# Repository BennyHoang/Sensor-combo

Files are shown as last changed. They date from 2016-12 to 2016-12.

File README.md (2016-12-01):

# Sensor-combo
M2M solution

# Oppgavebeskrivelse
Skolen har akkurat flyttet inn i nytt bygg og vi har opplevd at luften noen ganger er dårlig i klasserommene. Målet for eksamen i M2M er å ende opp med noe som kan bli
en permanent løsning for å overvåke læringsmiljøet, slik at man på sikt kan få det bedre. Dataene som løsningen samler inn skal brukes av elevene på M2M faget, men
også av Driftsavdelingen og andre linjer ved skolen. Det må derfor publiseres på en plattform som er enkelt tilgjengelig for alle som ønsker tilgang.
Sensor-nodene skal samle inn data om temperatur, fuktighet, lysnivå, bevegelse og CO2-nivå målt i PPM. Å sørge for at sensorene produserer riktige data er en del av
oppgaven, så om man trenger å gjøre kalibrering eller andre tilpasninger må dette dokumenteres. Hvordan man tenker å bygge og plassere nodene bør også
dokumenteres.

Sensor-noden skal lages med enten LoRa radio eller Particle Photon:
- Velger man LoRa radio, må man skrive en liten Gateway som kan sende dataene videre til internett. Om noen av dere trenger å låne en ekstra LoRa radio som Gateway,
gi meg beskjed så snart som mulig. Det er ikke krav om å bruke PubSub for LoRa, da jobbing med Gateway er forventet å ta litt ekstra tid.
- Velger man Particle Photon må man basere klienten på en PubSub løsning (f.eks. MQTT).
Du må argumentere for hvorfor du velger den ene fremfor den andre løsningen. Det at vi har mer erfaring med Photon bør ikke være et argument.
I tillegg til en radio, skal man ha med følgende sensorer i noden:
- DHT11 sensor
- Photoresistor
- PIR sensor
- MH-Z19 CO2 sensor (ikke MQ7 som er en CO-sensor!)

Sensor-nodene skal rapportere og lagre dataene på en valgfri skytjeneste. Det skal lages en klient som bør fungere på enten mobil eller stasjonær PC. Her skal man
kunne lese av status for mer enn ett rom og det bør også være mulig å kunne se historiske data. Klienten bør minimum ha en grafisk fremstilling av dataene over tid.

Det må lages en trinnvis dokumentasjon for hvordan man setter opp både klient og server. Denne skal være enkel å følge for en som ikke har samme erfarings-grunnlag
som vi har bygget opp i løpet av skoleåret. Den dere skriver dokumentasjonen for er altså en som ikke har brukt Photon eller LoRa Feather noe særlig før. Alle valg av
tjenester må begrunnes og det må dokumenteres hvordan løsningen skal kunne skaleres til å dekke både Fjerdingen og Vulkan Campus. 

Utover selve oppgaven skal det leveres dokumentasjon og kode som beskriver:
- Sensornode m/nødvendige biblioteker
- Skytjeneste
- Klient
- Skalering av løsningen utover en enkelt node
- Sikkerhet
- Valg av radio-løsning

Dokumentasjonen skal inneholde en video som viser hele løsningen i bruk. Den skriftlige dokumentasjonen bør være såpass god at andre skoler også kan sette opp en
tilsvarende løsning.
OBS!

Sensor-delen av denne oppgaven har dere langt på vei allerede gjort, men det holder ikke å lagre data til Particle Cloud. Denne oppgaven bygger videre på den første og
målet er at dere har bygget en komplett ende til ende implementasjon av et sensor-nettverk. Hvis dere skrev god dokumentasjon på sensor-noden i Oppgave 1, kan dere
gjerne gjenbruke noe av dette, men både klient og server-løsning er annerledes og må dokumenteres skikkelig. I tillegg skal kommunikasjonen med server-tjenesten være
annerledes enn i forrige løsning, så det bør være litt av hvert å bryne seg på her!

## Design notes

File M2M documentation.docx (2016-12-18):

# Documentation

# Oppgaven

Oppgaven går ut på å lage en løsning som kan overvåke løringsmiljøet slik at man på sikt kan få bedre oversikt over skolen sin tilstand.

Video: https://www.youtube.com/watch?v=nkPM_7XQKms

# Valg av enhet

Løsningen er bygget opp med Particle Photon som tar i mot data og sender dem til Microsoft sitt skytjeneste. Grunnen til at det ble valgt Particle Photon over LoRa radio er fordi løsningen kan lett bli satt opp uten å måtte konfigurere radiofrekvens etter hvor man befinner seg. Dette betyr at løsningen kan enkelt settes opp i en skole i Kina uten å måtte gjøre noe ekstra spesial tilpasninger.

LoRa frekvenser

- EU: 863-870 Mhz
- AU: 915-928 Mhz
- US: 902-928 Mhz
- CN: 779-787 Mhz

I tillegg til dette må man planlegge hvordan man skal sette opp infrastrukturen til LoRa. Man må stille spørsmål som:

- Hvilken rekkevidde får vi innendørs?
- Klarer vi å nå helt ned i kjelleren?
- Hvor bør Gateaway-radion stå?

Med Particle Photon, som har tilgang til wifi slipper man å tenke på alt dette. Her trenger man bare å tenke på hvor i rommet man skal plassere sensor-noden. I tillegg til dette har Particle en veldig bra dokoumentasjon på hvordan man kan sende data over HTTP. Dette gjør det lettere å kunne koble seg til en skytjeneste (i dette tilfellet Microsoft Azure).

# Arkitektur

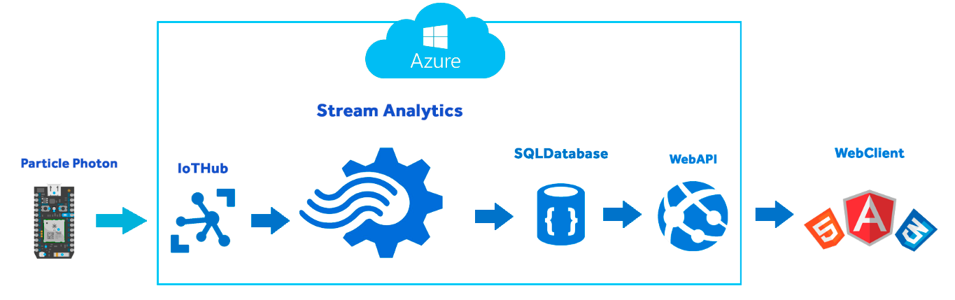
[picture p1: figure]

Her er en figur som illustrer hvordan dataen flyter fra enheten til nettsiden. IoT hub ligner veldig mye på EventHub, men den støtter 2-veis kommunikasjon over protokoller som MQTT eller AMQP. I tillegg til dette har Azure IoT hub «device management> der man kan registrere og forvalte alle sine enheter fra ett sted. MQTT gir for eksempel fordelen av å ha mindre «overhead» i protokollen, samt at den støtter callback funksjonalitet, dvs at du kan trigge metoder direkte på device. På den andre siden har Particle Cloud API også veldig god støtte for å snakke med enheten din på sin side. Les mer her om Azure IoT hub vs Azure Event Hub: https://docs.microsoft.com/en-us/azure/iot-hub/iot-hub-compare-event-hubs

## Setup Azure IoT Hub

For å kunne sette opp Azure IoT Hub, trenger du først en microsoft konto(outlook.com). Deretter kan du registrere Azure kontoen din her: https://azure.microsoft.com/nbno/free/?WT.srch=1&wt.mc_id=AID_SEM_

Particle og Microsoft nå partnere, så dette gjør det mye enklere å kunne integrere enheten mot microsoft sine produkter. Dette gjør det mulig for oss å bruke andre tjenester i Azure som:

- Azure Machine Learning (Predikere sensordata?)
- Notification Hub
- Stream Aanalytics
- PowerBI

Gjennom hele prossessen I opprettelse av applikasjoner i Microsoft Azure kan det lønne seg å være tålmodig da det tar tid før ting er ferdig opprettet.

For å kunne sette opp Azure IoT Hub må du navigere deg til Azure portalen: www.portal.azure.com Trykk på + ikonen på sidebaren, deretter trykk på Internet of Things > IoT Hub

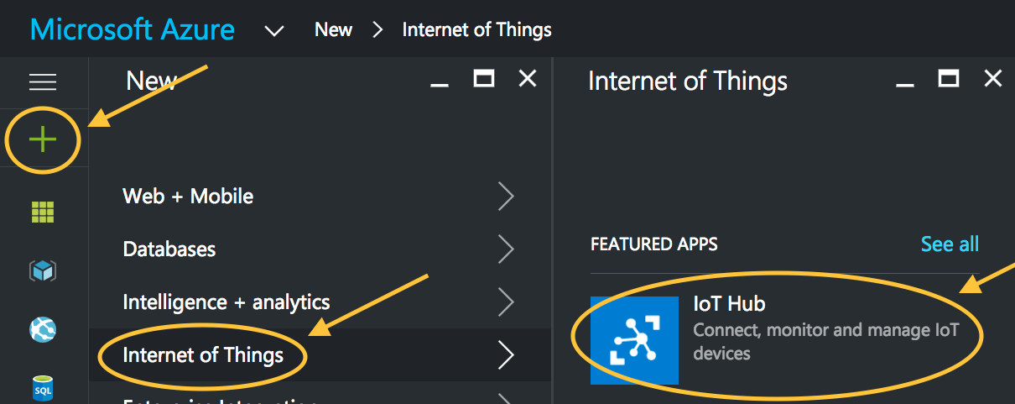
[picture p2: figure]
Create an IoT Hub

(Hvis du har vanskeligheter med å finne den, kan du også søke på IoT Hub i søkebaren)

Deretter vil en ny fane poppe opp, bruk disse instillingene hvis du vil teste løsningen fort og eksperimentere uten at ting skal koste penger. Det vil ta litt tid før IoT Huben din er oppe og kjører.

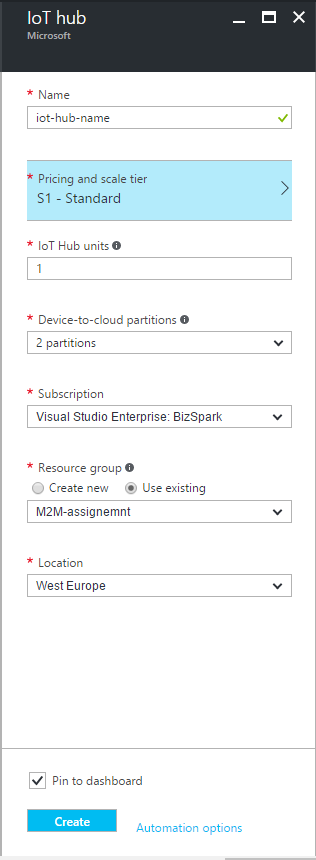
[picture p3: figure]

Hvis du velger Free-plan vil det ikke være mulig å oppgradere den til en av de andre tier i senere tidspunkt. Velger du Free vil det bare være for testing. Navnet til IoT-huben må du huske til senere for å kunne lykkes med integreringen. Bruk også resource group for å lett kunne gruppere dine applikasjoner under en gruppe. Dette gjør det lettere hvis du skal slette den til senere tidspunkt.

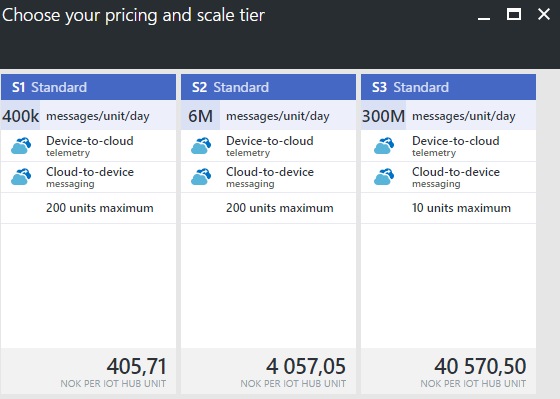
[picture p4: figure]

Det er ganske mye man kan gjøre for bare 405 kr i mnd (prisene endrer seg etter som valutakursene endrer seg). Dette avhenger selvfølgelig på hvor ofte du sender meldinger og hvor mange enheter som sender meldinger til IoT Huben.

Legg til Shared Access Policy

For å gjøre det mulig for Particle å snakke med IoT huben din, må du legge til en shared access policy. Dette er også på grunn av sikkerhetsmessige årsaker, med shared access policy lager du en regel som bare gjelder for din particle integrasjon. Når IoT Huben er ferdig spunnet opp, klikk på ikonet fra dashboardet, deretter klikk på shared access policies > + Add. Gi din policy write, read og device connect permissions.

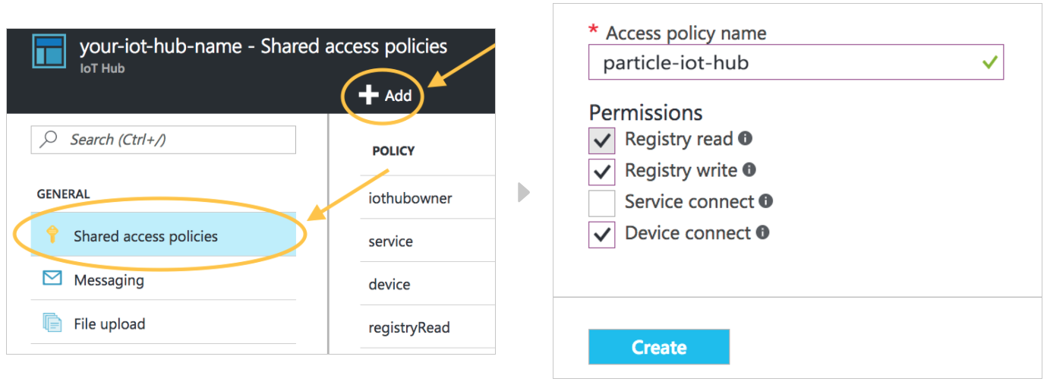
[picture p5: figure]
Create shared IoT Hub policy

For at din particle enhet skal kunne ha vellykket integrasjon trenger du begge policy name og policy primary key. Du kan finne dette ved å klikke på policy navnet som du nettop har opprettet.

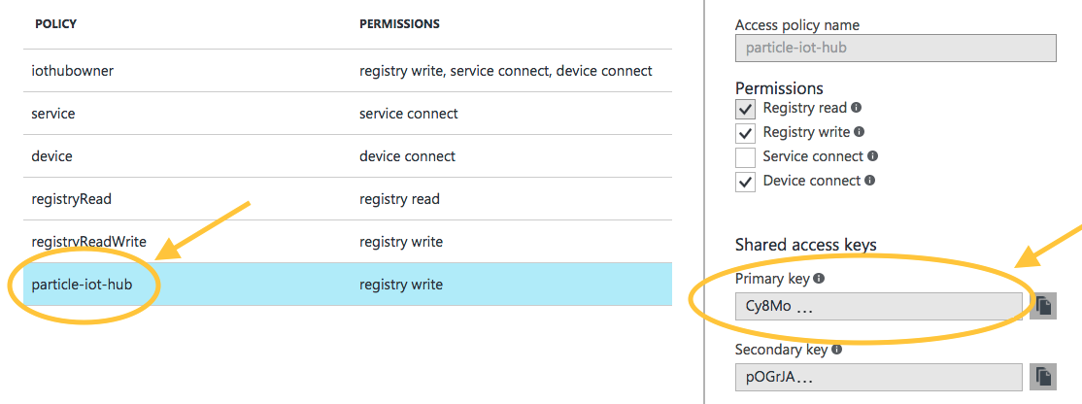
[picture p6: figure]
Access shared IoT Hub policy info

Alle nøkkler fra applikasjonene i Azure har ending med « = », hvis du er usikker på at du har kopiert hele koden, kan du se på slutten av strengen om den har « = ». Ellers kan du klikke på ikonet for å kopiere nøkkelen. Når dette er ferdig kan vi begynne å konfigurere instillingene i Particle.

## Particle Console

Naviger deg inn til www.console.particle.io for å aktivere Azure IoT Hub Integration.

(Den er fortsatt under beta, så noe kan være litt ustabilt)

Videre i konfigurasjonen vil du støte på disse feltene:

- Event Name: Dette er navnet på eventet som vil trigge datapublisering til Azure IoT Hub. Dette vil bli trigget når du kaller på Particle.publish() metoden fra Particle.
- IoT Hub Name: Navnet som du ga IoT Huben. I dette tilfellet: iot-hub-name
- Shared Access Policy Name: Navnet til Shared Access Policy. I dette tilfellet: particle-iot-hub
- Shared Access Policy Key: Nøkkelen fra shared access policy name
- Device: Hvis du vil at dette skal gjelde alle particle enheter, velg: “Any”, hvis du vil at det bare skal gjelde din enhet må du velge enheten med respective navn.

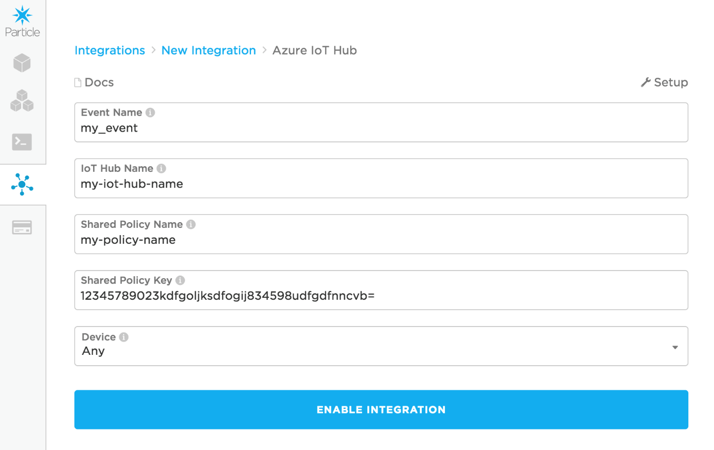
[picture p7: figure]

Videre klikker du på Advanced settings for å kunne sende din spesial tilpasset JSON. Hvordan webhook variablene fungere kan du lese mer om her: https://docs.particle.io/guide/tools-and-features/webhooks/#webhook-variables

Kode:

{

"carbondioxide": "{{C2}}",

"temperature": "{{t}}",

"humidity": "{{h}}",

"light": "{{l}}",

"motion": "{{m}}",

"timecreated": "{{SPARK_PUBLISHED_AT}}",

"guid": "{{SPARK_CORE_ID}}",

"location": "{{loc}}"

}

# Particle Photon

Utstyrsliste for Particle Photon:

- MH-Z19
- DHT11
- Photoresistor
- PIR

Før du i det heletatt begynner å koble opp hele systemet og laste opp kode, kan det lønne seg å bare koble hvert komponent hver for seg og teste hver for seg. Dette kan du f.eks gjøre ved å teste gjennom analogRead(PIN).

Set up Particle Photon: https://docs.particle.io/guide/getting-started/start/core/

## Koblingsskjema

PIR | Particle Photon | Data
VCC | VCC | Bevegelse
Data | D0
GND | GND

DHT11 | Particle Photon | Data
VCC | VCC | Temperatur: Celcius & Farenheit Fuktighet
GND | GND
D-OUT | D2
A-OUT | Ingen

Photosensor | Particle Photon | Data
A-OUT | A5 | Lys
GND | GND

MH-Z19 | Particle Photon | Data
PWM | D1 | CO2 (Carbondioksid)
GND | GND
VCC | VCC

Jeg fant ikke delen for MH-z19 i fritzing, men det holder nok å forholde seg til koblingsskjema også. Vær oppmerksom på at PIR-sensoren kan oppføre seag litt merkelig i starten. Da hjelper det å justere Sensetivity og delay.

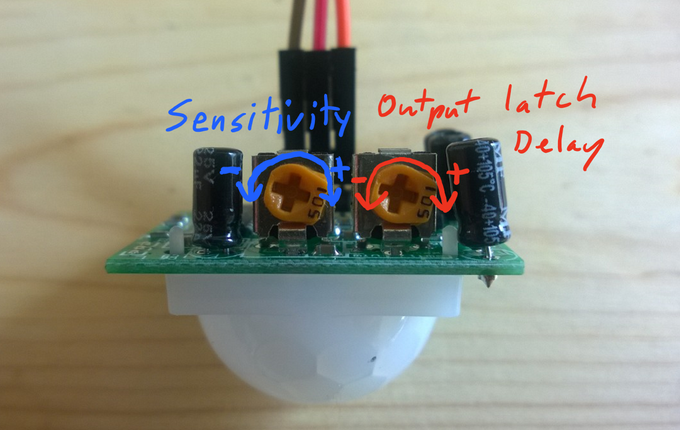
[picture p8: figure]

## Kode

Til dette prosjektet lastet jeg ned local IDE for å kunne jobbe med filer. Fordelen med dette er når man har så mange sensorer som nå, blir det lettere å lage objekter av sensorene. IDE kan lastes ned her: https://www.particle.io/products/development-tools/particle-local-ide

Ulempen med IDE-et er at man ikke kan inkludere biblioteker på like lett måte som online IDE-et. Dette må du selv laste ned og legge til i prosjektet. En løsning på dette (som jeg gjorde) var å gå inn på online IDE, finne det biblioteket jeg ville ha og replikere filene i local IDE.

Deretter, for at alle .h filer skal fungere må du inkludere #include "application.h" i respektive .filer. Dette er for å kunne bruke Particle sitt bibliotek.

Det er også mulig å bruke www.build.particle.io men da må du være oppmerksom på at oppdelingen av sensorene ikke vil fungere. Du må legge alle koden i en fil.

## Test om data blir sendt

Det finnes flere måter å se om dataen blir sendt. Fra particle sin side holder det å sjekke ut consoll loggen fra nettleseren eller ved å kjøre particle subscribe mine fra CLI. Jeg har forholdt meg til consollen nettleseren.

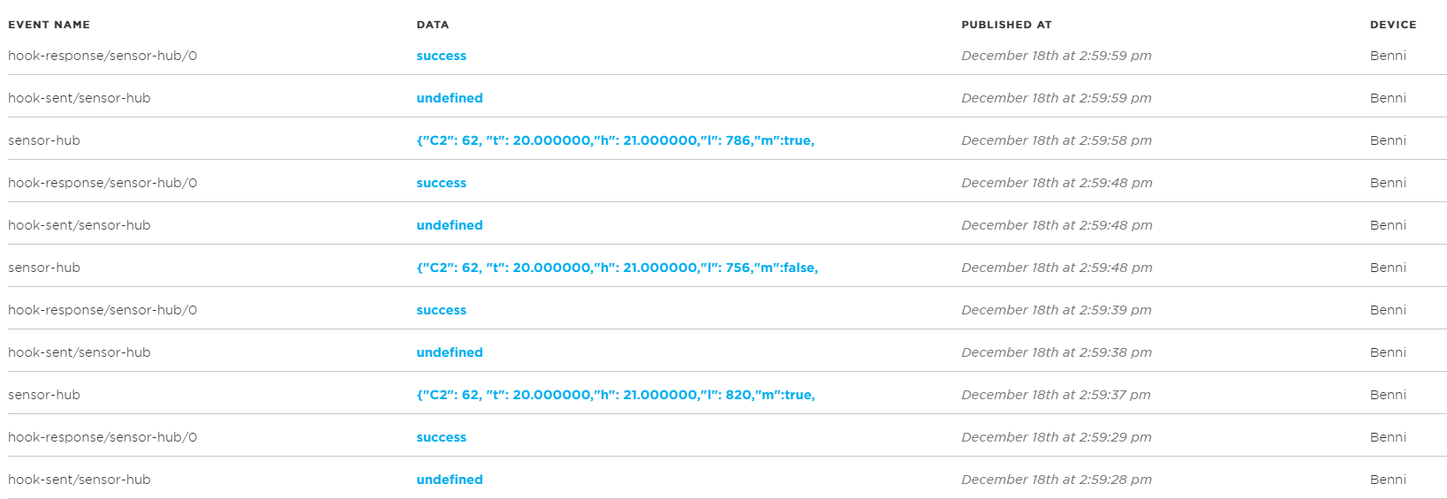
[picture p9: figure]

Fra Azure sin side kan det lønne seg å sjekke ut iothub-explorer som er en npm-pakke. https://github.com/Azure/iothub-explorer

Når alt er på plass og meldingene blir sendt uten error vil particle enheten din bli registrert i IoT Huben.

Du vil også kunne se om kvoten din per dag blir brukt opp eller ikke.

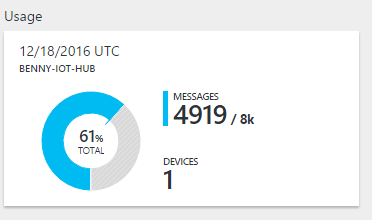
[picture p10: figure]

## Stream Analytics

På grunn av tid og erfaring vil denne delen skje gjennom den gamle portalen. Det er ingenting i veien å gjøre dette gjennom den nye portalen, men forrige oppgave var jeg avhengig av å gjøre alt i gamle portalen på grunn av støtte for Service bus og eventhub. Ingenting i den denne løsningen er egentlig avhengig av den gamle portalen.

Naviger til www.manage.windowsazure.com

Stream Analytics er det verktøyet vi vil bruke for å kunne sveise sammen data fra enheten og skrive til en database. Den fungerer som en publisher og en subscriber. I dette tilfellet vil den ta inputstream fra IoT Hub og deretter output til en SQL-Database. Meldingene som blir sendt til IoT Hub vil bli slettet over tid og derfor trenger vi SQL-Database til å kunne lagre historiske data.

For å opprette database trykker du på SQL Databases og trykk på new

Når databasen er ferdig opprettet må vi legge til tabeller og attributter. For å gjøre dette lett, klikk inn på Open in Visual Studio

Let etter SQL serveren som databasen ligger i og opprett ny tabell.

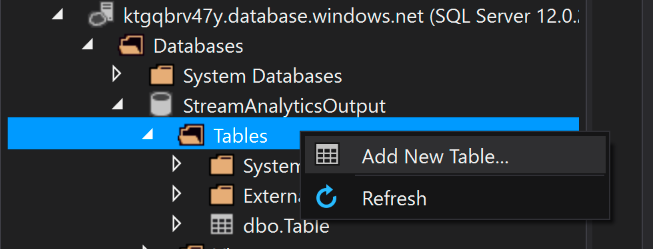
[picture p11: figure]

Det går ann å bruke Databasedesign vinduet til å legge til i databasen, men lim inn dette for å spare tid.

CREATE TABLE [dbo].[Table] (

[Id] INT IDENTITY (1, 1) NOT NULL,

[temperature] FLOAT (53) NULL,

[humidity] FLOAT (53) NULL,

[light] INT NULL,

[motion] NVARCHAR (MAX) NULL,

[timecreated] DATETIME NULL,

[guid] NVARCHAR (MAX) NOT NULL,

[carbondioxide] INT NULL,

[location] NVARCHAR (MAX) NULL,

PRIMARY KEY CLUSTERED ([Id] ASC)

);

Opprette Stream Analytics

På samme måte som database leter du etter en lignende ikon bare for stream analytics

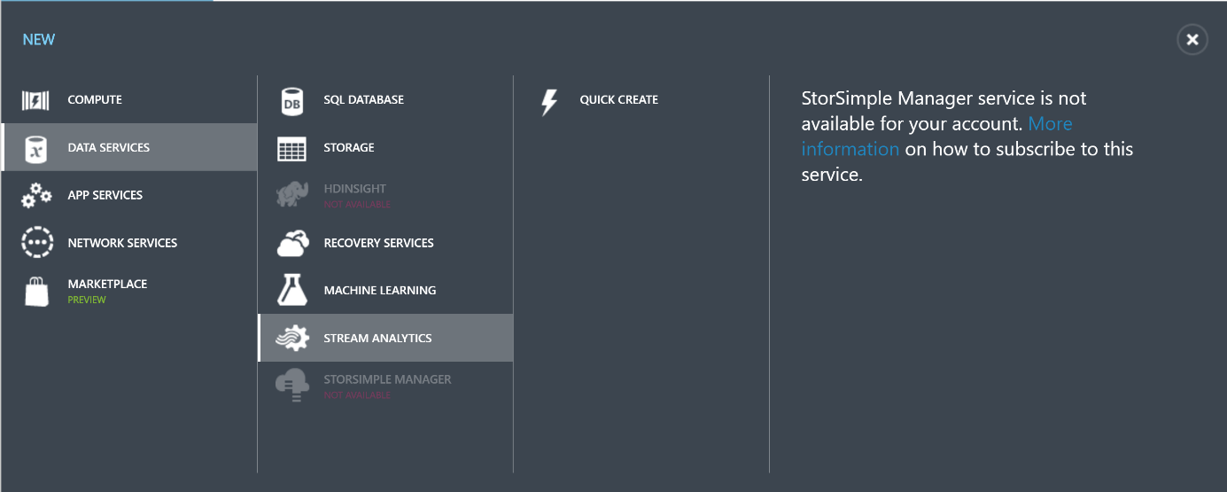
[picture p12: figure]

Vi vil først gå inn på inputs for å si til stream analytics hvor datakildene våres kommer i fra. Dette finner du i topmenyen

Trykk deretter på add input som befinner seg i footeren.

## Input

Step 1. Velg data stream

Step 2. Velg IoT Hub

## Output

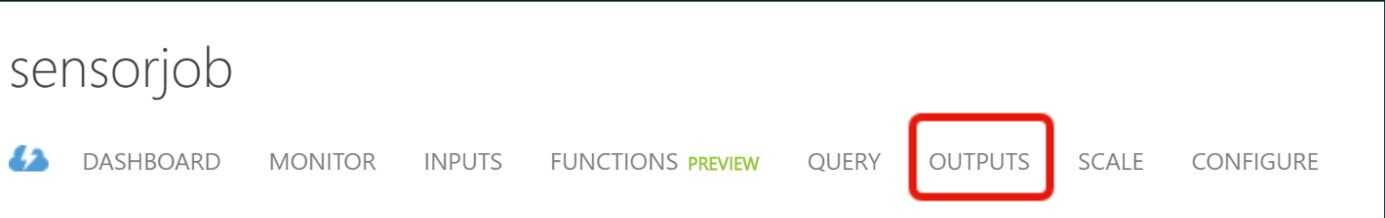
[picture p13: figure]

Klikk på Add output og deretter velg SQL-Database

Fyll inn feltene med det du har configurert databasen din med. Her er det viktig at du referer til samme tabell. I mitt tilfelle kalte jeg bare min for Table.

Videre går vi til Query som er i samme meny som Input og Output. Her vil vi kunne kjøre spørringer slik at det som kommer fra input datastrømmen vil bli lagt inn i output som er vår database. Legg så inn dette scriptet i vinduet

SELECT

temperature, humidity, light, motion, timecreated, guid, carbondioxide, location

INTO

StreamAnalyticsOutput

from

iotsensorhub;

## Test runs

Før du spinner opp jobben kan det lønne seg å kjøre test på dataene. Dette kan spare deg for masse tid da oppstart av jobben tar lang tid og aggregeringen av dataene tar lang tid. Jeg brant meg veldig på dette under prosjektet da webhooken min hadde feil i JSON, men skjønte ikke hva som var problemet til jeg testet dataene.

Gå først inn på input for å laste ned sample data.

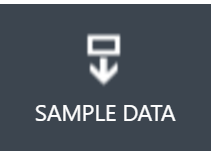
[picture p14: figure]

Her kan du velge hva slags intervall dataene dine skal komme fra. Hvis det var en tidsperiode der din particle ikke fungerte, kan du lett filtrere bort dette.

Når den er ferdig lastet trykk på details for å laste ned dataene.

Bruk: https://jsonformatter.curiousconcept.com til å formatere JSON slik at det blir lettere å se dataene. Dette gjør du ved å åpne JSON filen, klipper ut innholdet og limer den inn i vinduet. Hvis alt her viser seg å være fint, betyr det at alle dataene som blir sendt fra din particle photon er safe og det er ikke noe feil der som må rettes opp.

Naviger deg videre inn til query og trykk på Test knappen.

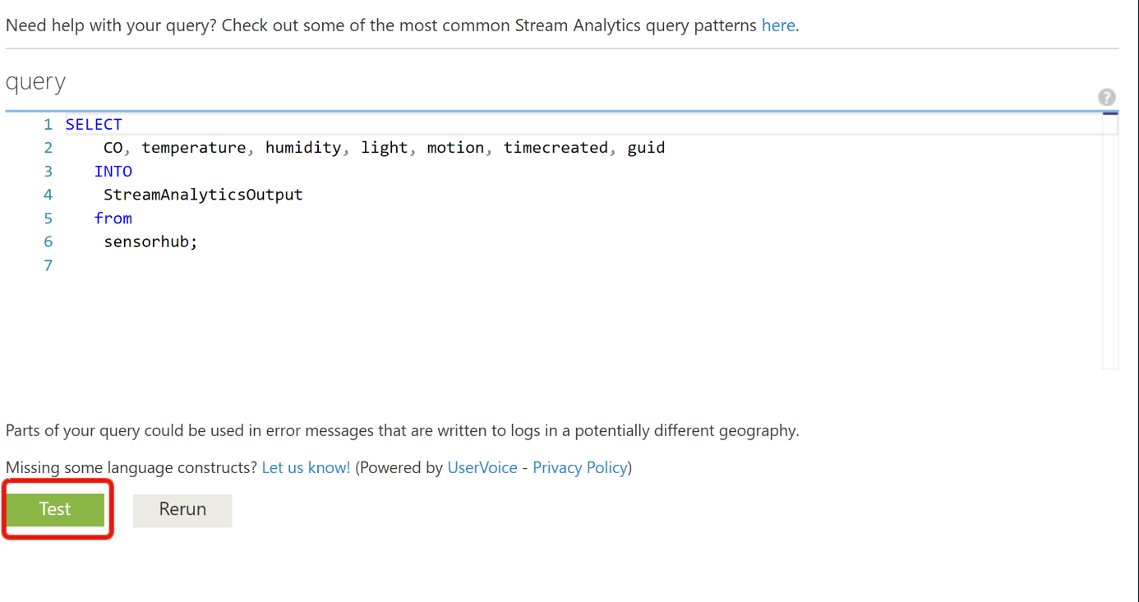
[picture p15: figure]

Last opp JSON filen du fikk fra input. Da vil du også kunne få ut hvordan det vil se ut i databasen.

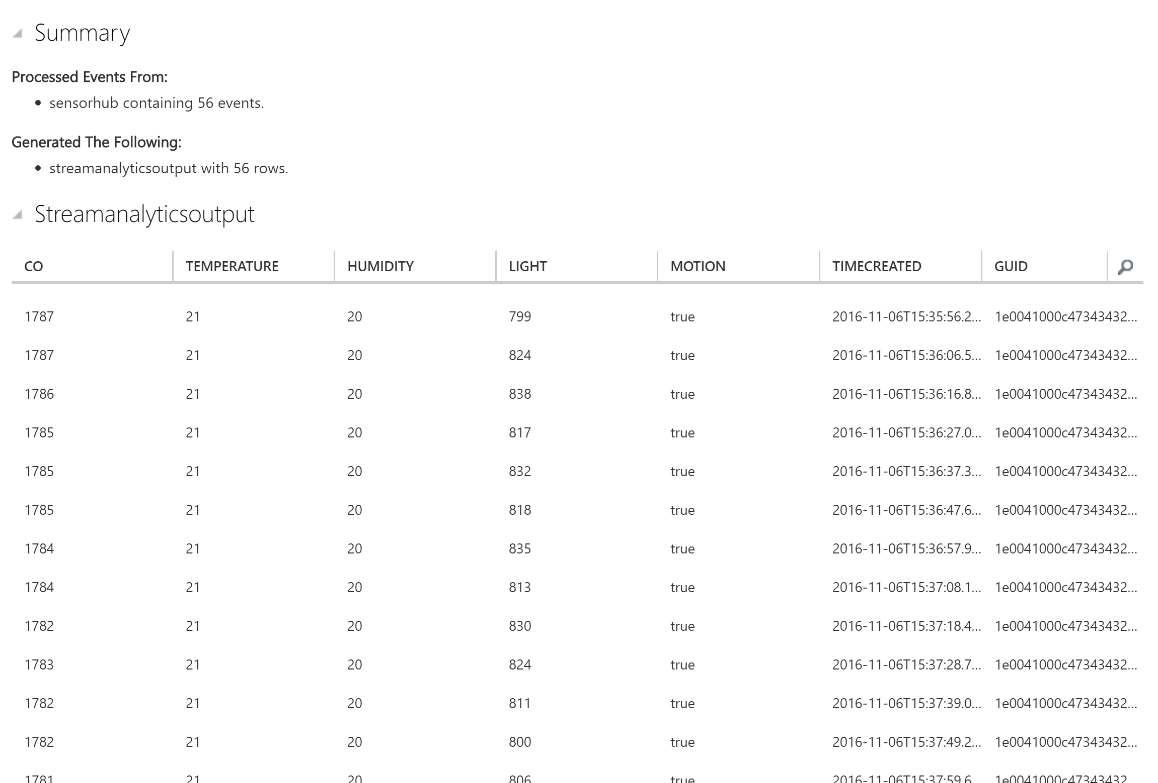
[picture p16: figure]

Hvis alt ser ut som det skal fungere, kan du bare starte jobben og samle inn sensor data.

# Web Api i C#

## Oppsett av prosjektet

- Start med å lage ett nytt prosjekt ved å gå inn på file > new > Project ...
- Velg ASP.Net Web application (.NET framework)
- Velg Empty og huk av på Web API. Det er også mulig å publisere api-et til azure hvis det er ønsket.

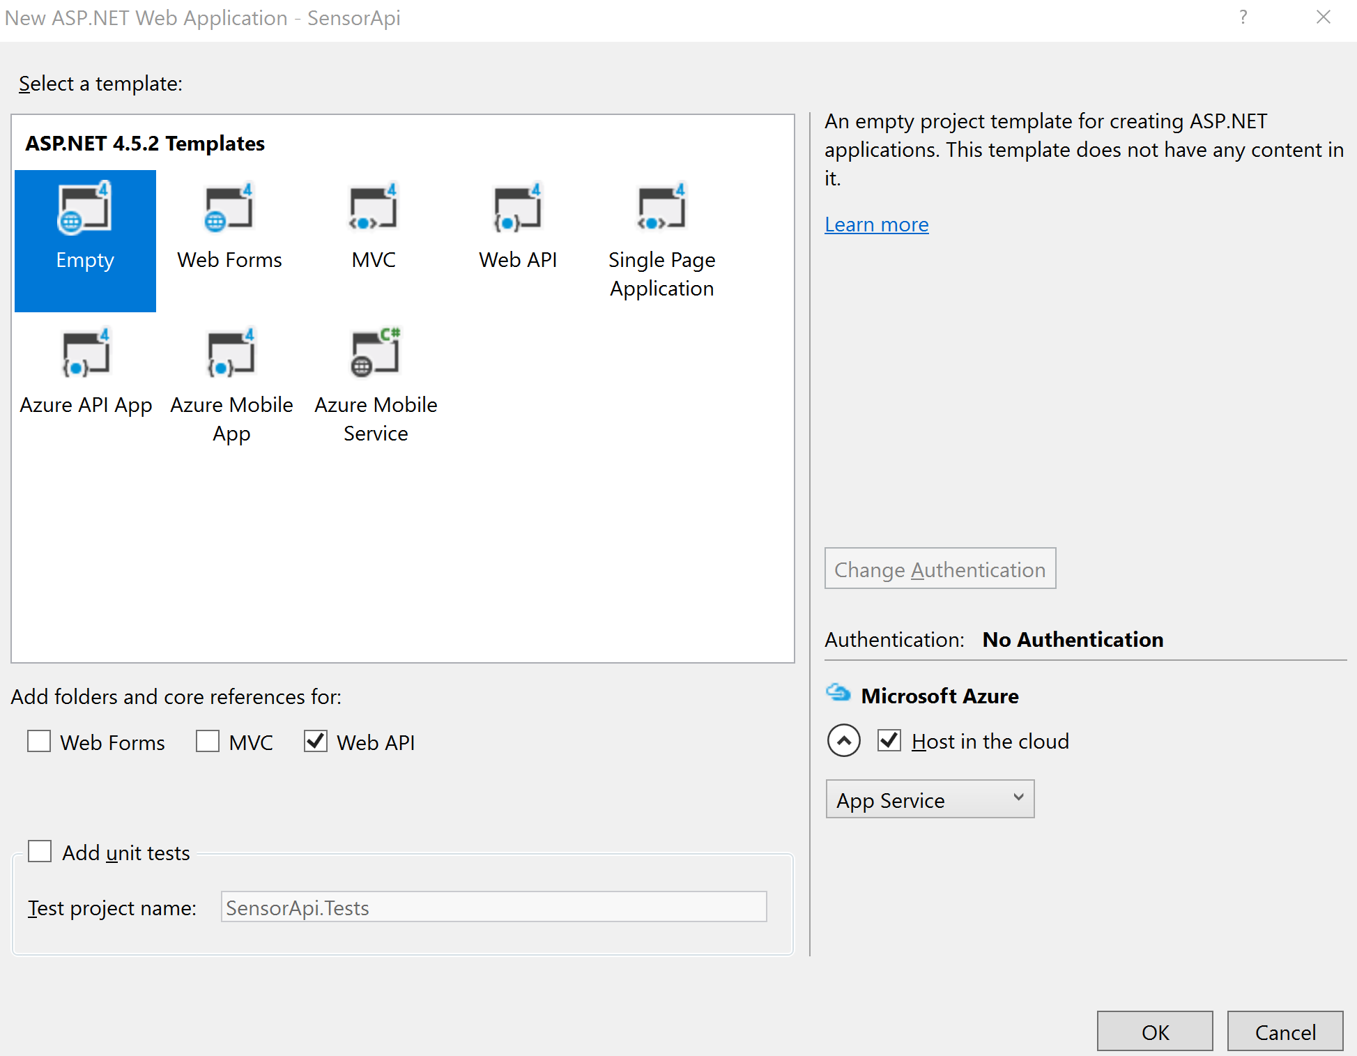
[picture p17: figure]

## Lag Modell

- Legg til LINQ to SQL Classer ved å høyreklikke på Models.
- Gå inn på SQL Server Object Explorer i venstre tab og velg din SQL server fra Azure. Hvis det ikke er allerede opprettet sql server kan du klikke på add sql server ikonet.
- Du vil deretter få dialogboks om hvilken server du skal koble deg opp mot. Velg riktig database og deretter fyll inn feltene med riktig info.

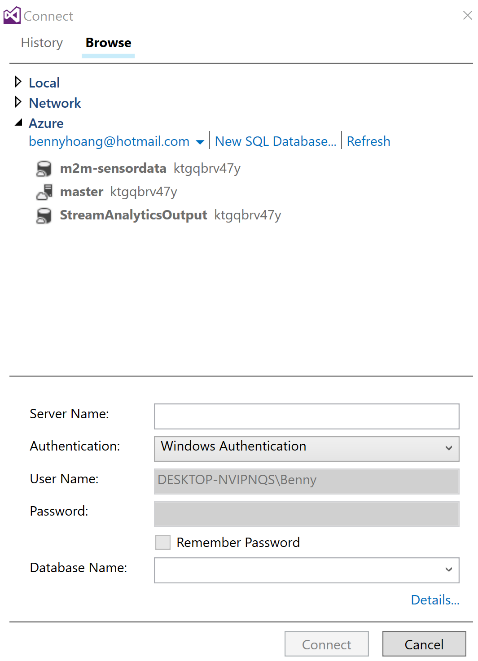
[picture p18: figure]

- Etter å ha åpnet sql serveren din kan du finne tabellen hvor sensordataene ligger. Deretter dra hele tabellen inn i det hvite vinduet i dbml filen. I mitt tilfelle heter tabellen min dbo.Table

For å gjøre det lettere i kode gir jeg tabellen et mer logisk og spesefikt navn slik at det blir lettere å holde tungen rett i munnen. Dette gjør du ved å dobbelklikke på tittelen, deretter lagre filen. På denne måten lager vi et objekt som representerer data i web-apiet. ASP.NET Web API kan automatisk serialisere modellen din til formater som JSON eller XML.

## Lag Controller

- Høyreklikk på Controller > Add > Controller...

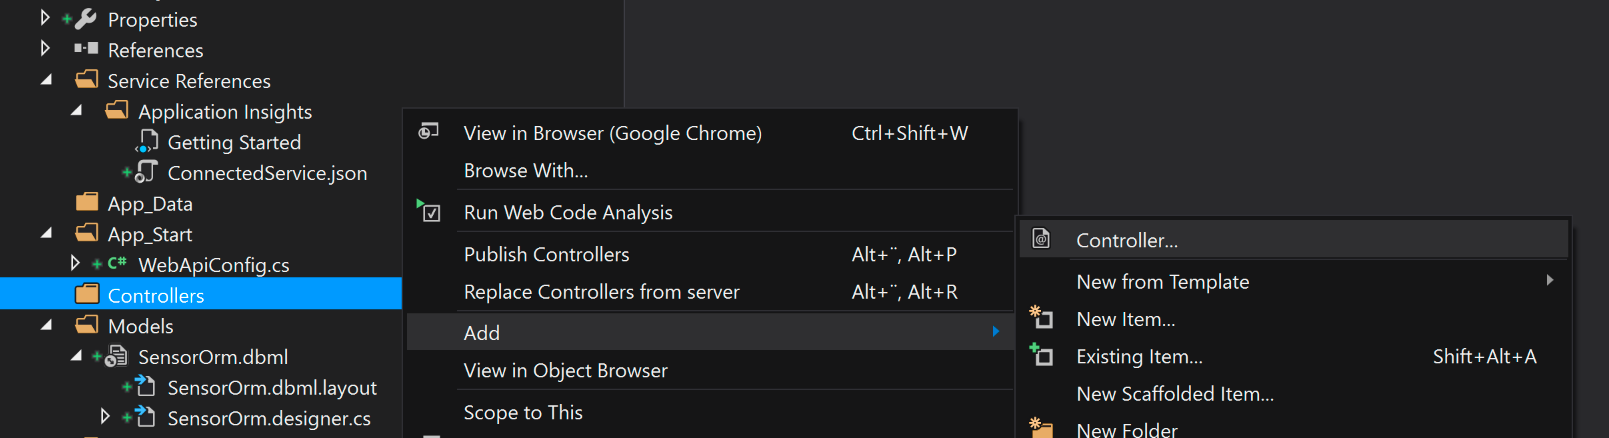
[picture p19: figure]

- I Scaffold dialogboksen velg Web API 2 Controller – Empty
- Gi deretter logisk navn til kontrolleren. Det er viktig å ha med prefixen «Controller» på slutten av kontrolleren din slik at applikasjonen kan vite at dette er en kontroller. Navnet må også følge PascalCase for at det skal fungere.
- Vi lager en metode som henter alt fra databasen og populerer den til en liste. For at vi skal kunne få tilgang til modellene som er opprettet må du inkludere modellene. Dette gjør du ved å skrive:

using <NAMESPACE>.Models;

Namespace er det prosjektet ditt heter. I mitt tilfelle skriver jeg using SensorApi.Models;
Apiet ligger publisert her: http://sensorapi2030394.azurewebsites.net/api/sensor/getallsensordata

# Frontend

Jeg skal ikke gå i dybden om hvordan man legger opp koden her da dette er mer fritt fram hvordan man har tenkt til å visualisere data osv.

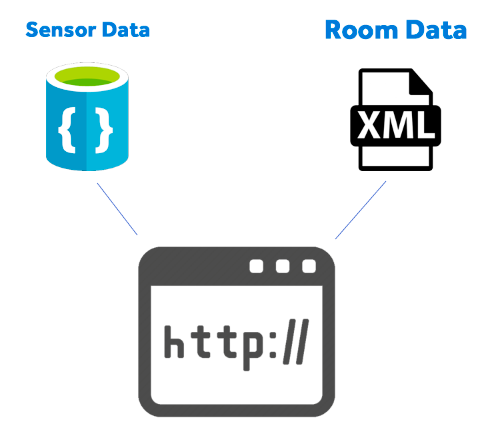
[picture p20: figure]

Løsningen er laget for driftansvarlige. Her er det mulighet til å lage nye rom og refere sensor til respektive rom. Valg av XML som database vil ikke være skalerbar, men med tanke på prototyping har jeg valgt å bare gå for xml for å demonstrere hvordan brukerflyten er.

List:

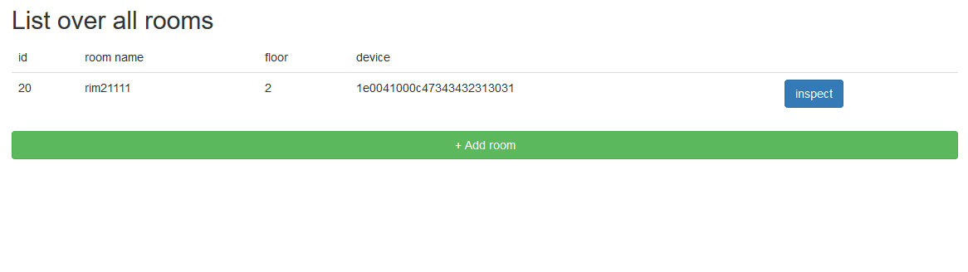
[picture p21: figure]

Her er tanken at vi kan ha oversikt over alle rom, for å så gå inn og lese av status på rommet.

Add room:

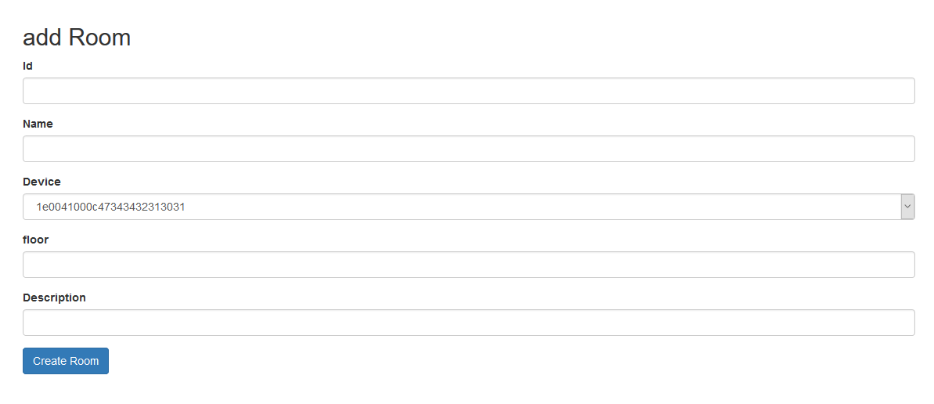
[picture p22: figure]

Når man legger til rom er det tenkt at man også kan velge hvilken enhet som skal bli lagt til i rommet.

Room:

Når rommet er opprettet vil man kunne gå og se på status på rommet. På grunn av at jeg bare har en sensor til rådighet kan jeg bare legge til ett rom og få en type sett med data. Jeg har filtrert ut dataene her på Device ID, så hensikten her er å kunne se på data fra spesefikk device. Når man legger til ny rom med annen sensor vil grafene se annerledes ut.

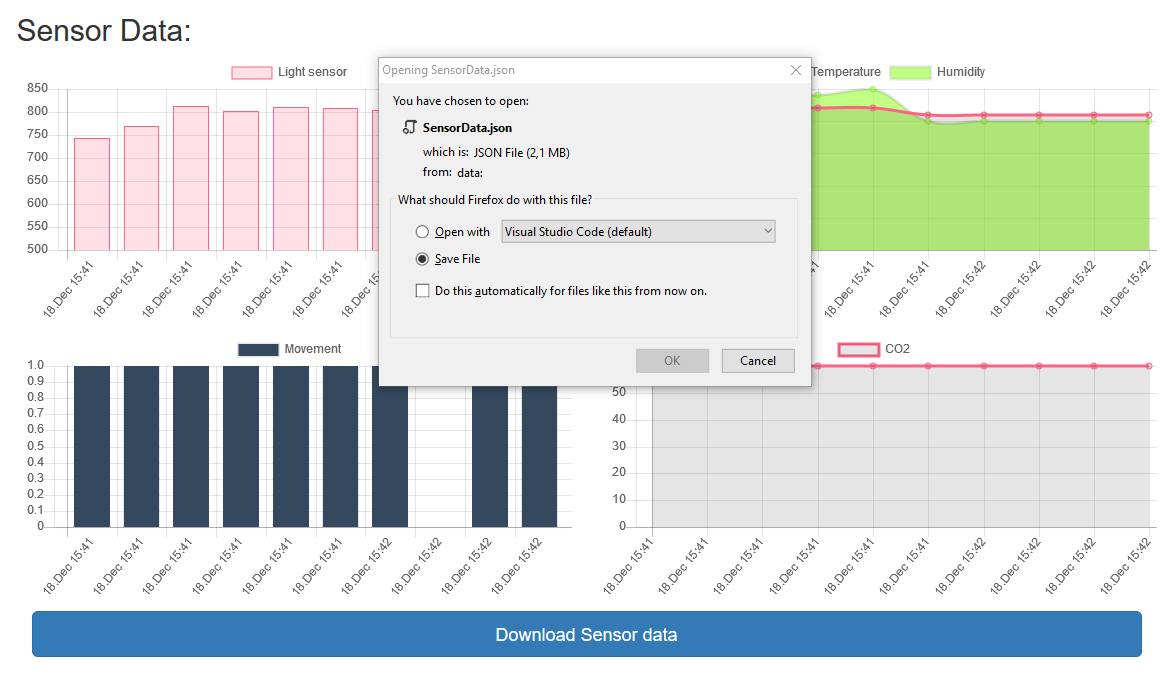
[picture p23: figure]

Det er også mulighet til å laste ned hele datasettet. Her er det tiltenkt at den personen som adminstrerer kan eksportere dataene og behandle dem gjennom ønsket program i tillegg til dette. Optimalt sett ville det kanskje vært best å kunne filtrere dataene etter dato osv (slik som man gjør i stream analytics for testing av data).

## Room Name = Location @Particle

En ting som er verdt å merke her er når man oppdaterer romnavnet, så vil det også bli oppdatert i particle sin location variabel.

Javascript:

Particle Photon:

Dette vil bli satt til bake til hva location var satt til hvis du skrur av og på enheten. Løsningen her kunne vært å titte litt på EEPROM for å manipulere firmware. https://docs.particle.io/reference/firmware/photon/#eeprom

# Avslutning

Front end er ikke en komplett løsning, men er en fin måte til å demonstrere hva mulighetene etter at man har satt opp Azure apps og Particle Photon.

Jeg er heller ikke sikker på om alle sensor data er 100% korrekt eller kan gjøres mer treffsikker. Jeg har i denne oppgaven fokusert mest på å kunne få data til å bli eksponert til en web-api slik at de dataene kan bli brukt av forskjellige plattformer. Dette kan være Web, mobil eller desktop applikasjoner. Det kan til og med være en raspberry pi med LCD-skjerm som henter dataene over http ?

## Known bugs

Stream Analytics

Jeg har støtt på en bug i stream analytics. Det hender noen ganger at particle sender data når DHT skriver ut NaN. Da vil den slite med å skrive til databasen pga typesjekking. Du kommer helt sikkert til å støte på:

Encountered error trying to write 1 event(s): Cannot convert from property 'temperature' of type 'System.String' to column 'temperature' of type 'System.Double'

Dette vil resultere med at stream analytics ikke får til å skrive data til databasen. Løsningen på dette vil være å endre på Error policy i azure portalen (Her kan du bruke den nye portalen). Bytt fra retry til drop. Dette vil sørge for at når particle sender data som ikke kan bli parset av stream analytics, er det kanskje bedre å bare ignorere dem, og vente til neste lesning. Hvis du har lengre intervall per lesning kan det lønne seg å heller CAST dataene i «Query» istedenfor. F.eks

temperature = CASE WHEN temperature = 'NaN' THEN 0.0 ELSE CAST(temperature AS Float),

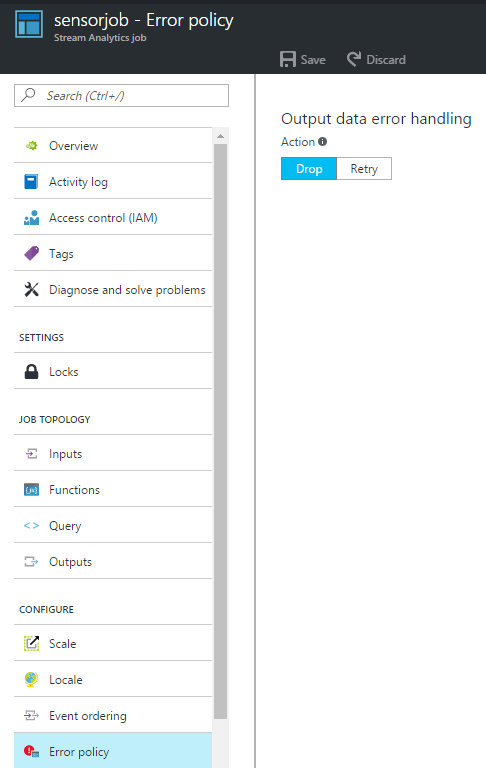
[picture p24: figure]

# Kilder

https://www.sparkfun.com/datasheets/Sensors/Biometric/MQ-7.pdf

https://www.hackster.io/falafel-software/pir-sensor-with-a-photon-particle-cloud-and-a-uwa-97e79b

https://cdn-learn.adafruit.com/downloads/pdf/pir-passive-infrared-proximity-motion-sensor.pdf

https://www.asp.net/web-api/overview/getting-started-with-aspnet-web-api/tutorial-your-first-web-api

https://www.linkedin.com/pulse/getting-started-azure-iot-services-stream-analytics-rob-tiffany

https://github.com/BennyHoang/webutvikling_innlevering_2

https://docs.particle.io/tutorials/integrations/azure-iot-hub/#example-use-cases

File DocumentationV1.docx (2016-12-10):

# Sensor nettverk

# Utstyr som trengs

- MQ-7
- MH-Z19
- DHT11
- Photoresistor
- PIR
- Microsoft Account
- Microsoft Azure
- Visual Studio 2015
- Particle Local IDE

Før du i det heletatt begynner å koble opp hele systemet og laste opp kode, kan det lønne seg å bare koble hvert komponent hver for seg og teste hver for seg.

# Kobling

PIR | Particle Photon
VCC | VCC
Data | D0
GND | GND

MQ-7 | Particle Photon
VCC | VCC
GND | GND
D-OUT | ingen
A-OUT | A0

DHT11 | Particle Photon
VCC | VCC
GND | GND
D-OUT | D2
A-OUT | Ingen

Photosensor | Particle Photon
A-OUT | A5
GND | GND

MH-Z19 | Particle Photon
PWM | D1
GND | GND
VCC | VCC


# Particle Photon

Til dette prosjektet lastet jeg ned local IDE for å kunne jobbe med filer. Fordelen med dette er når man har så mange sensorer som nå, blir det lettere å lage objekter av sensorene. IDE kan lastes ned her: https://www.particle.io/products/development-tools/particle-local-ide

Ulempen med IDE-et er at man ikke kan inkludere biblioteker på like lett måte som online IDE-et. Dette må du selv laste ned og legge til i prosjektet. En løsning på dette (som jeg gjorde) var å gå inn på online IDE, finne det biblioteket jeg ville ha og replikere filene i local IDE.

Deretter, for at alle .h filer skal fungere må du inkludere #include "application.h" i respektive .filer. Dette er for å kunne bruke Particle sitt bibliotek.


Dette er JSON payload som blir sendt til eventhuben i Azure. For å generere denne bruker vi «particle webhook» i CLI.

Ved å skrive particle webhook list kan du se liste over dine webhooks.


Når du skal legge til/ endre på webhooken så må du først slette den (hvis den allerede eksisterer) ved å skrive particle webhook delete <ID> etterfulgt med particle webhook create .\webhook.json

# Azure

I azure bruker vi disse:

Apper

Service Bus

Stream Analytics

SQL Databases

WebApps

Service bus er ikke støttet i den nye portalen enda. Derfor forholder vi oss mest til den gamle portalen: www.manage.windowsazure.com

## Service Bus

Generell info om service bus: https://azure.microsoft.com/nb-no/services/service-bus/

Fra Particle sender vi meldinger til Azure ved hjelp av Eventhubs som ligger i service bus. For å opprette en service bus må du klikke på dette ikonet. Dette finner du i sidebaren.

Klikk deretter på Create som befinner seg i footeren


Deretter vil du få en dialogboks hvor du configurerer service bus. Allerede her er det viktig å ha logiske navnkonvensjoner. Det er helt opp til deg hvordan du gjør det. Jeg har lagt til prefikser på slutten av hvert navn. Eks: ns, hub, job.


Velg instillingene som er vist over. Det vil ta noen minutter før Service bus er klar for bruk.

Når Azure er ferdig med å fyre opp Service Bus vil du få beskjed om det i notification baren nederst.

Inne på Service Busen din kan du gå inn i Event Hub som ligger i øverste navigasjonsmeny.


Trykk deretter på new nederst til venstre > quick create.


Kan hende at man kan lage eventhub direkte når man trykker på create i Service Bus, men for sikkerhetsskyld gjorde jeg dette for å få til en fungerende løsning. Denne prossessen var det jeg gjorde i forrige innlevering så jeg forholdt meg til det. Det kan være en minor update som har skjedd i mellom tiden. Men jeg ser allerede her at det blir opprettet to namespaces. Det kan være at siden forrige gang så må man ha med -ns på slutten av name-spacet. Dette har jeg enda ikke prøvd.

For å kunne få Particle Photon til å sende meldinger til Eventhuben må vi gjøre noen konfigureringer først. Naviger inn til configure for å sette instillinger på eventhuben.


Med tanke på sikkerhet kan man konfigurere shared access policy. Her kan vi bestemme hva slags rettigheter de ulike policiene kan ha. Dette er viktig med tanke på sikkerhet. Jeg har satt opp en del policies for fremtidlig bruk.


Det er også her du finner shared access key til particle webhook. Det er på denne måten webhooken kan klare å gjøre HTTP-POST request til Event hub.

## Stream Analytics

Generell info om Stream Analytics: https://azure.microsoft.com/nb-no/services/stream-analytics/

I vårt prosjekt vil Stream Analytics være den tjenesten som tar input fra Event hub og output til en SQL-Database.

På samme måte som Service bus leter du etter en lignende ikon bare for stream analytics

Jo mer du bruker tjenesten jo mer vant blir du til å opprette ting da det er mye av det samme.

Vi vil først gå inn på inputs for å si til stream analytics hvor datakildene våres kommer i fra. Dette finner du i topmenyen


Trykk deretter på add input som befinner seg i footeren.

## Input

Step 1. Velg data stream

Step 2. Velg Event Hub

Step 3.


Her har vi allerede konfigurert det som trengs i eventhuben. Der ser man også fordelen med å ha riktig navn allerede fra starten av. Hadde man gått for noe som test-1 test-2 test-3... hadde vi allerede sett her at det blir vanskelig.

Instillingene i input ser slik ut:


## Output

Før vi går videre i output må vi lage en database først.

Naviger deg inn hit og trykk igjenn på new.

Når databasen er ferdig opprettet må vi legge til tabeller og attributter. For å gjøre dette lett, klikk inn på Open in Visual Studio

Let etter SQL serveren som databasen ligger i og opprett ny tabell.


Det går ann å bruke Databasedesign vinduet til å legge til i databasen, men lim inn dette for å spare tid.

CREATE TABLE [dbo].[Table] (

[Id] INT IDENTITY (1, 1) NOT NULL,

[CO] INT NULL,

[temperature] FLOAT (53) NULL,

[humidity] FLOAT (53) NULL,

[light] INT NULL,

[motion] NVARCHAR (MAX) NULL,

[timecreated] DATETIME NULL,

[guid] NVARCHAR (MAX) NULL,

PRIMARY KEY CLUSTERED ([Id] ASC)

);

Nå kan vi endelig å videre til Output. For å lage Output navigerer vi til output i top menyen.


Klikk på Add output og deretter velg SQL-Database

Fyll inn feltene med det du har configurert databasen din med. Her er det viktig at du referer til samme tabell. I mitt tilfelle kalte jeg bare min for Table.

Videre går vi til Query som er i samme meny som Input og Output. Her vil vi kunne kjøre spørringer slik at det som kommer fra input datastrømmen vil bli lagt inn i output som er vår database. Legg så inn dette scriptet i vinduet

SELECT

CO, temperature, humidity, light, motion, timecreated, guid

INTO

StreamAnalyticsOutput

from

sensorhub;


## Test runs

Før du spinner opp jobben kan det lønne seg å kjøre test på dataene. Dette kan spare deg for masse tid da oppstart av jobben tar lang tid og aggregeringen av dataene tar lang tid. Jeg brant meg veldig på dette under prosjektet da webhooken min hadde feil i JSON, men skjønte ikke hva som var problemet til jeg testet dataene.

Gå først inn på input for å laste ned sample data.


Her kan du velge hva slags intervall dataene dine skal komme fra. Hvis det var en tidsperiode der din particle ikke fungerte, kan du lett filtrere bort dette.

Når den er ferdig lastet trykk på details for å laste ned dataene.

Bruk: https://jsonformatter.curiousconcept.com til å formatere JSON slik at det blir lettere å se dataene. Dette gjør du ved å åpne JSON filen, klipper ut innholdet og limer den inn i vinduet. Hvis alt her viser seg å være fint, betyr det at alle dataene som blir sendt fra din particle photon er safe og det er ikke noe feil der som må rettes opp.

Naviger deg videre inn til query og trykk på Test knappen.


Last opp JSON filen du fikk fra input. Da vil du også kunne få ut hvordan det vil se ut i databasen.


Hvis alt ser ut som det skal fungere, kan du bare starte jobben og samle inn sensor data.

# Web Api i C#

## Oppsett av prosjektet

- Start med å lage ett nytt prosjekt ved å gå inn på file > new > Project ...
- Velg ASP.Net Web application (.NET framework)
- Velg Empty og huk av på Web API. Det er også mulig å publisere api-et til azure hvis det er ønsket.


## Lag Modell

- Legg til LINQ to SQL Classer ved å høyreklikke på Models.


- Gå inn på SQL Server Object Explorer i venstre tab og velg din SQL server fra Azure. Hvis det ikke er allerede opprettet sql server kan du klikke på add sql server ikonet.
- Du vil deretter få dialogboks om hvilken server du skal koble deg opp mot. Velg riktig database og deretter fyll inn feltene med riktig info.


- Etter å ha åpnet sql serveren din kan du finne tabellen hvor sensordataene ligger. Deretter dra hele tabellen inn i det hvite vinduet i dbml filen. I mitt tilfelle heter tabellen min dbo.Table

For å gjøre det lettere i kode gir jeg tabellen et mer logisk og spesefikt navn slik at det blir lettere å holde tungen rett i munnen. Dette gjør du ved å dobbelklikke på tittelen, deretter lagre filen. På denne måten lager vi et objekt som representerer data i web-apiet. ASP.NET Web API kan automatisk serialisere modellen din til formater som JSON eller XML.

## Lag Controller

- Høyreklikk på Controller > Add > Controller...


- I Scaffold dialogboksen velg Web API 2 Controller – Empty


- Gi deretter logisk navn til kontrolleren. Det er viktig å ha med prefixen «Controller» på slutten av kontrolleren din slik at applikasjonen kan vite at dette er en kontroller. Navnet må også følge PascalCase for at det skal fungere.
- Vi lager en metode som henter alt fra databasen og populerer den til en liste. For at vi skal kunne få tilgang til modellene som er opprettet må du inkludere modellene. Dette gjør du ved å skrive:

using <NAMESPACE>.Models;

Namespace er det prosjektet ditt heter. I mitt tilfelle skriver jeg using SensorApi.Models;

- Legg til følgene kode


Denne metoden returner de 10 siste loggede sensor data. Dette er for å lett kunne se hva som ble logget sist istedenfor å bla igjennom en hel historikk med data.

Kjør koden og gå inn på ~/api/sensor så vil du kunne se loggen som er blitt publisert fra eventhuben.

Apiet mitt ligger publisert her: http://sensorapi2030394.azurewebsites.net/api/sensor

# Next steps

## Webside

Nå som Web-Api er på plass, skal det bli lettere å lage en nettside som henter sensordata. Akkurat nå har ikke løsningen noe brukerverdi. Ingen vanlige folk liker å lese JSON format (enda).

## Optimalisere Sensordata

Sensordataene som sendes inn kan kanskje forbedres mye mer. Jeg har vurdert om ikke alle data skal sendes med en gang eller ikke. Det har har jeg desverre ikke fått så mye tid til å titte på. Hovedfokuset var å få disse sensordataene til å kunne flowe gjennom stream analytics til en database. Eksempler på dete kan være at den leser av 10 verdier og tar gjennomsnittet av det for å så returnere en sensor data.

# Kilder

https://www.sparkfun.com/datasheets/Sensors/Biometric/MQ-7.pdf

https://www.hackster.io/falafel-software/pir-sensor-with-a-photon-particle-cloud-and-a-uwa-97e79b

https://cdn-learn.adafruit.com/downloads/pdf/pir-passive-infrared-proximity-motion-sensor.pdf

https://www.asp.net/web-api/overview/getting-started-with-aspnet-web-api/tutorial-your-first-web-api

https://www.linkedin.com/pulse/getting-started-azure-iot-services-stream-analytics-rob-tiffany

https://github.com/BennyHoang/webutvikling_innlevering_2

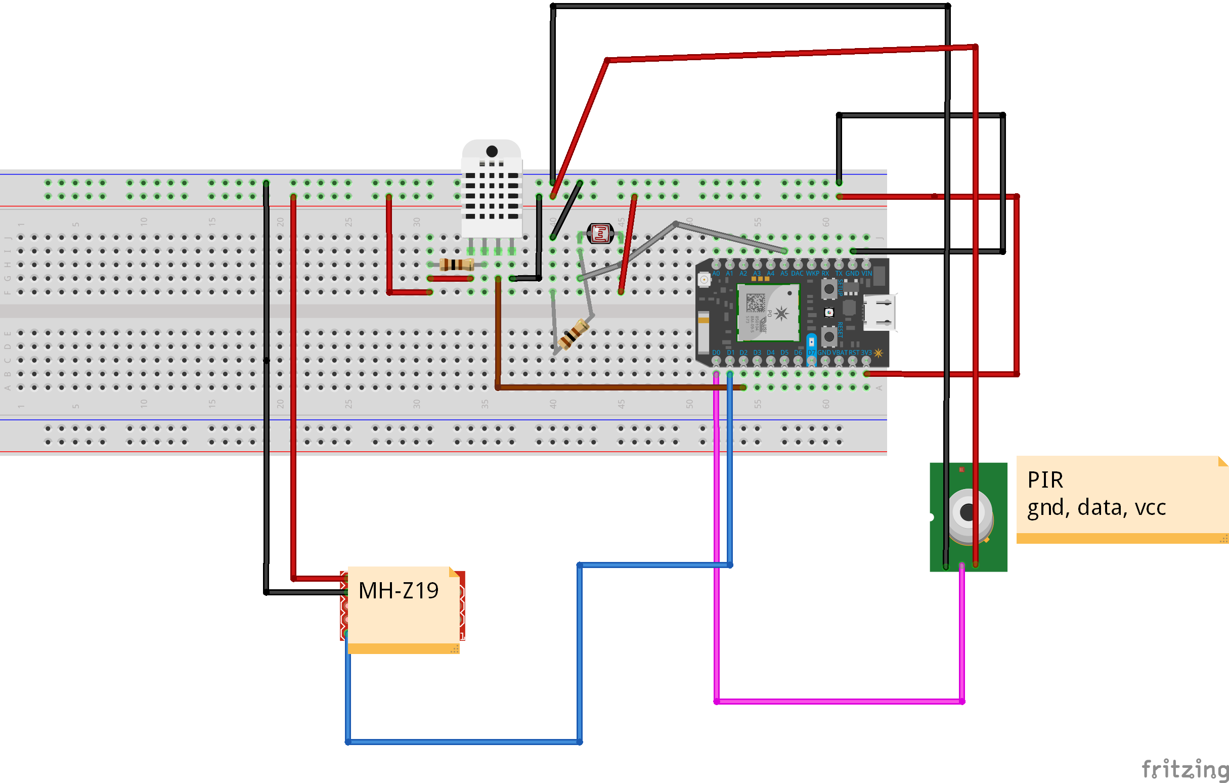
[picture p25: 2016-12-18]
fritzing_bb.png

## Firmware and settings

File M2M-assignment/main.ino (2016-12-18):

#include "mq7.h"
#include "mhz19.h"
#include "pir.h"
#include "dht.h"
#include "light_sensor.h"

MQ7Sensor MQ7;
MHZ19Sensor MHZ19;
PIRSensor PIR;
DHT11Sensor DHT_11;
LIGHTSensor LIGHT;
//Delay for production:
//unsigned long sendDelay = 2*60*1000;
char location[64] = "default_value";
//Delay for debugging:
unsigned long sendDelay = 10000;
void setup() {
    Particle.function("setLoc", setLoc);
    Serial.begin(9600);
    MQ7.init();
    MHZ19.init();
    PIR.init();
    DHT_11.init();
    LIGHT.init();
    Serial.print("Preheating");
    delay(10000);

}

void loop() {

generatePayload();
delay(sendDelay);
}

int setLoc(String command){
  command.toCharArray(location,64);
  return 0;
}


void generatePayload(){
  //INITIALIZING SENSOR VALUES
  int lightValue = LIGHT.getSensorValue();
  int CO2 = MHZ19.getSensorValue();
  float humidity = DHT_11.getHumidity();
  float celcius = DHT_11.getCelcius();
  bool motion;

  Serial.print("light value= ");
  Serial.println(lightValue);
  Serial.println("=================================");
  // OUTPUT for CO2
  Serial.print("CO2 = ");
  Serial.println(CO2);
  Serial.println("=================================");

// OUTPUT for Motion
  if(PIR.calibrated())
  {
    PIR.readSensorValue();
    PIR.outputMotion();
    Serial.println("=================================");
    motion = PIR.getMotionStatus();
    Serial.println(motion);

  }else{
    Serial.println("Calibrating...");
    Serial.println("=================================");
  }

Serial.print("Humidity: ");
Serial.println(humidity);
Serial.println("=================================");
Serial.print("Celcius: ");
Serial.println(celcius);
Serial.println("=================================");
char payload[255];
snprintf(payload, sizeof(payload),"{\"C2\": %d, \"t\": %f,\"h\": %f,\"l\": %d,\"m\":%s, \"loc\":\"%s\"}",CO2,celcius,humidity,lightValue, motion ? "true": "false", location);

//String message = String("{\"C2\" : \"" + (String)CO2 + "\", \"t\" : \"" + (String)celcius + "\", \"h\" : \"" + (String)humidity + "\", \"m\" : \"" + (String)motion + "\", \"l\" : \"" + (String)lightValue + "\", \"loc\" : \"" + (String)location + "\"}");
//Publishes to eventhub
//Particle.publish("PublishSensorData",payload);
//Publishes to iotHub
Particle.publish("sensor-hub",payload,PRIVATE);

}

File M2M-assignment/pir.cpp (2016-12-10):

#include "pir.h"

PIRSensor::PIRSensor(){
  _calibrationTime = 10000;
  _val = 0;
  _state = LOW;
  _motion = false;
}

void PIRSensor::init(){
  Serial.begin(9600);
  pinMode(PIR_PIN, INPUT);
  pinMode(LED_PIN, OUTPUT);
}

bool PIRSensor::calibrated(){
  return millis() - _calibrationTime > 0;
}

void PIRSensor::readSensorValue(){
  _val = digitalRead(PIR_PIN);
}

void PIRSensor::outputMotion(){
  if(_val == HIGH){
    if(_state == LOW){
      //Particle.publish("designingiot/s15/motion");
      Serial.println("Motion detected");
      _state = HIGH;
      digitalWrite(LED_PIN, HIGH);
      _motion = true;
      setMotionStatus(_motion);
    }
  }else{
    if(_state == HIGH){
      Serial.println("motion ended");
      _state = LOW;
      digitalWrite(LED_PIN, LOW);
      _motion = false;
      setMotionStatus(_motion);
    }
  }
}

void PIRSensor::setMotionStatus(bool motion){
  _motion = motion;
}

bool PIRSensor::getMotionStatus(){
  return _motion;
}

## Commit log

2016-11-01 added DHT11 and light sensor
2016-11-01 added own object for light sensor
2016-11-01 shortened the payload text so everything gets sent
    [main.ino]
2016-12-15 edited more accurate reading on DHT sensor
2016-12-17 added download button
2016-12-17 removed sensorData.html
2016-12-18 wrapping up and finish exam
    [fritzing.fzz]
